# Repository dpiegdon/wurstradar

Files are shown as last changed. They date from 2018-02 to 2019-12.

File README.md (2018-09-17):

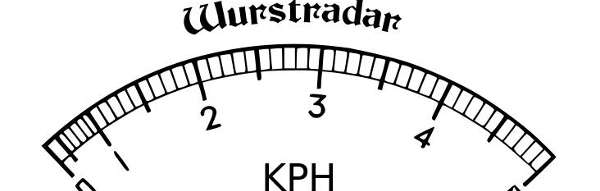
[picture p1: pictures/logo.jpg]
Wurstradar


Sausage radar. Simple doppler radar that fits into a sausage can.
Named after "Wurstblinker" from the german movie [Werner](https://www.youtube.com/watch?v=n31j2_dkaCo),
as it also is meant to be mounted on a motorcycle as an alternative to the speedometer.

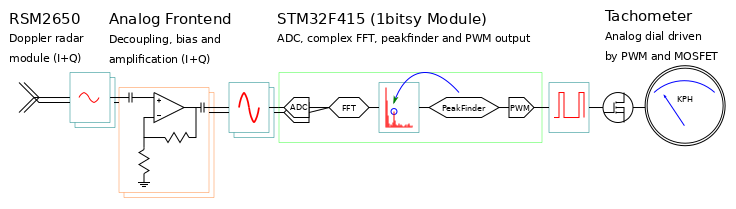
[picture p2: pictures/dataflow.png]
DataFlow


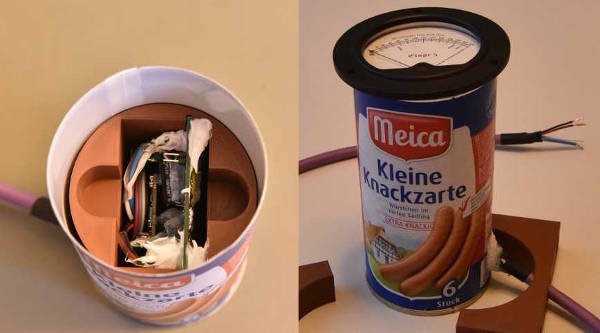
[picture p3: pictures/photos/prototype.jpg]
Prototype


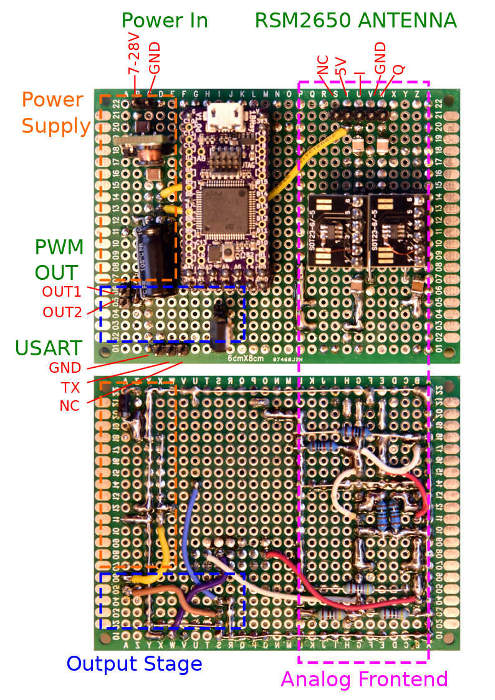
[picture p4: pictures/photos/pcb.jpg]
PCB


Required hardware
=================

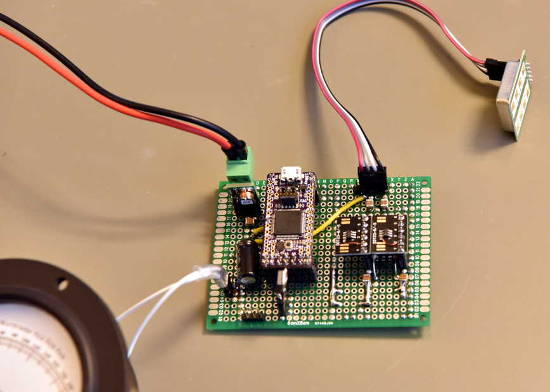
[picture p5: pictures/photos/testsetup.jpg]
TestSetup


RSM2650 Radar movement alarm unit (this probably is an Innosent IPS-265)

 * `http://www.produktinfo.conrad.com/datenblaetter/500000-524999/506343-da-01-en-RADARBEWEGUNGSM__MOD__STEREO_4_75__5_25V.pdf`
 * `https://www.innosent.de/fileadmin/media/dokumente/datasheets/IPS-265.pdf`

1bitsy STM32F415 on a tiny breakout board

 * `https://1bitsy.org/`

Used Simpson Voltmeter 5V as analog dial.

 * `https://www.google.de/search?q=simpson+5v+ac&tbm=isch`

Generic powerbrick to 5V

 * e.g. TI TPSM84205

A JTAG debugger.

 * e.g. Black Magic Probe

Required software
=================

Only `arm-none-eabi-gcc`.

Further plans and ideas
=======================

 * FMCW / Range Doppler (minor hardware change, complex firmware changes)

   The current antenna module (RSM2650) can be replaced with a module that supports a tuning
   voltage. Then, FMCW and Range-Doppler could be done. The tuning voltage could be supplied
   with the STM32 DAC, which already has some support code in the git history.

 * Improved signal quality and range (complex hardware changes)

   The analog frontend currently is a simple opamp amplifier with decoupling and biasing.
   Options are to increase the amplification, pick better opamps or dedicated LNAs.
   Automatic gain might me an option with that.

 * USB waveform output (simple firmware changes)

   Output both I and Q as a data stream via USB, so a connected computer can use them.

Compiling
=========

Clone first: `git clone --recursive https://github.com/dpiegdon/wurstradar.git`

Then build libopencm3: `cd wurstradar/libopencm3 && make`

Then build the firmware: `cd ../src && make` - 
you can set the measurement angle and its proper doppler frequency via
commandline: `make DOPPLER_HZ_PER_POINT1_KPH=314 MEASUREMENT_DEGREE=45`

Flash it to the 1bitsy. E.g. with a Black Magic Probe.

Team
====

 * David Owczarek - `david dot owczarek at googlemail dot com` - hardware

 * David R. Piegdon - [@dpiegdon](https://github.com/dpiegdon) - concept, firmware, hardware and assembly

 * Florian Schwanse - `florian at schwanse dot de` - 3d printed parts and case

 * Frank Terbeck - [@ft](https://github.com/ft) - concept and hardware

 * Iqbal Maraqa - `iqbal underscore maraqa at hotmail dot com` - analog dial face

 * Manoel Brunnen - [@mbrunnen](https://github.com/mbrunnen) - firmware

 * Martin Gritzan - [@mgritz](https://github.com/mgritz) - firmware

 * Sebastian Moenninghoff - `spsm at mailbox dot org` - 3d printed parts

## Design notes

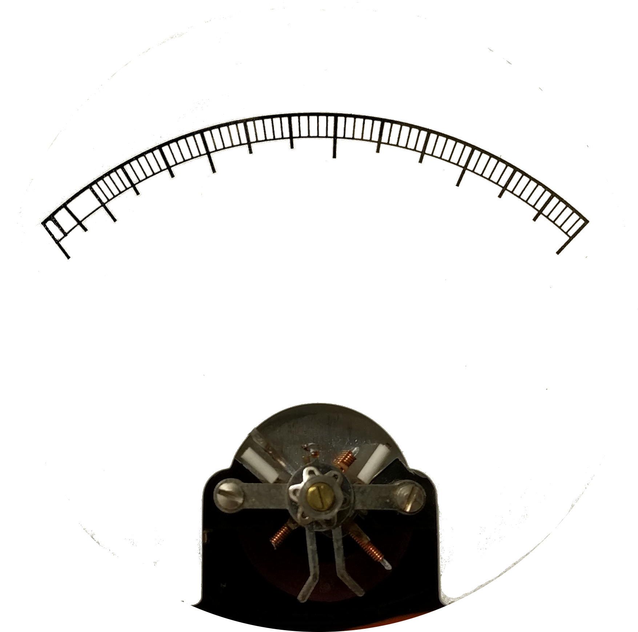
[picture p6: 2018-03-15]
pictures/faceplate/faceplate_scale.png

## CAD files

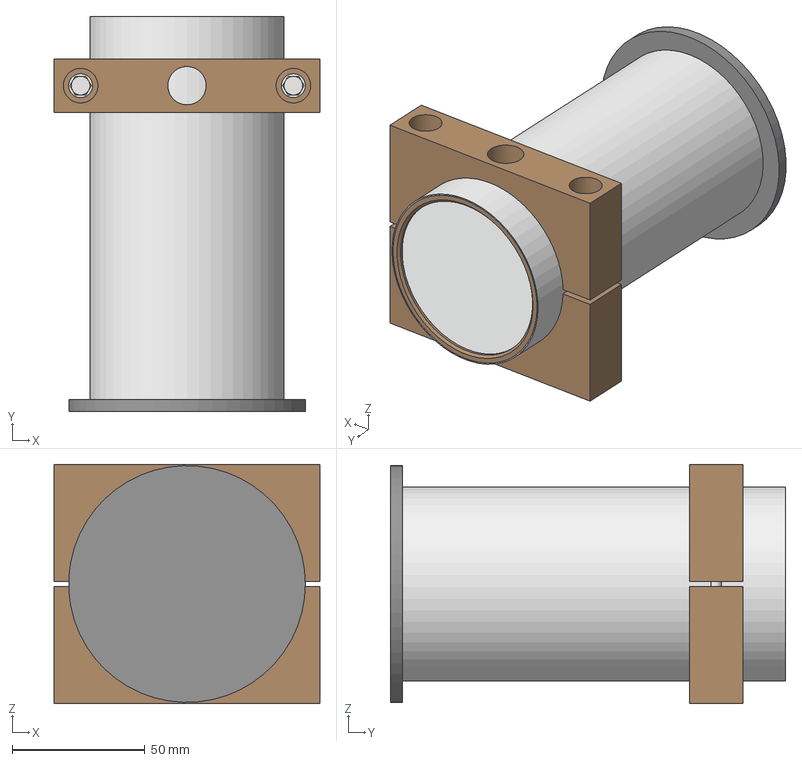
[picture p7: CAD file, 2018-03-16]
can-inlay/wurstradar_2018-03-15.stp
100.0 x 148.5 x 90.0 mm

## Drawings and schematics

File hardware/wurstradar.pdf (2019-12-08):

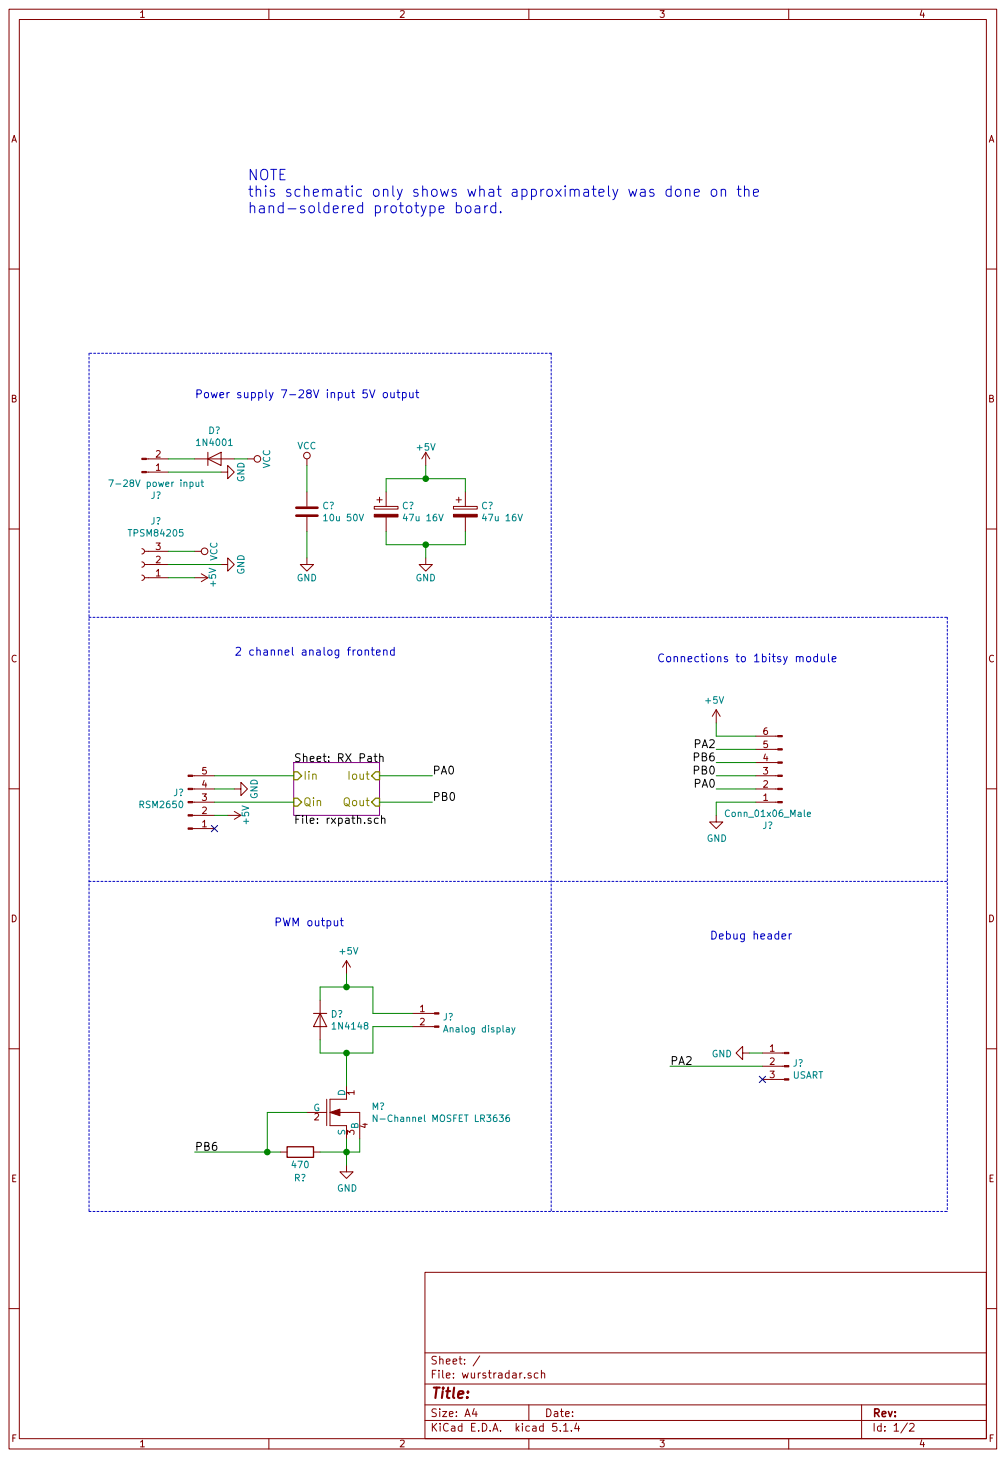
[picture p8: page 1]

NOTE
this schematic only shows what approximately was done on the
hand-soldered prototype board.

Power supply 7-28V input 5V output

47u 16V R? | J? Conn_01x06_Male GND +5V

PWM output +5V | | 1

Id: 1/2 Title: File: wurstradar.sch Sheet: /

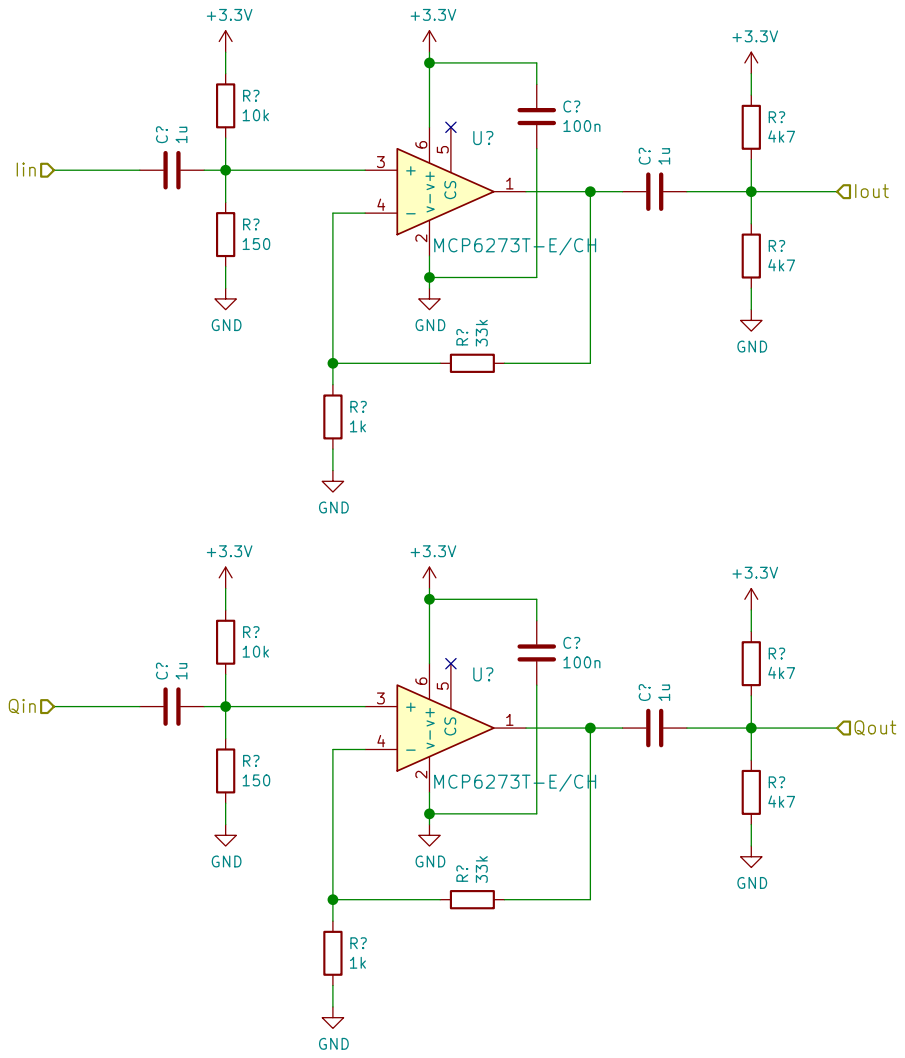
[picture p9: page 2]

File: rxpath.sch Sheet: /RX Path/

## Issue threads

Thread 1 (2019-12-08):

can't open the schematic file!

tek4ever, 2019-12-08:
what version of kiCad do you use for this schematic?

dpiegdon, 2019-12-08:
True, a current version of KiCad (5.1.4) required some remapping and a few things were unclear.
I updated the schematic and also exported as PDF.
But note that the schematic is only for documentation purposes. It is incomplete and only indicates what was done on the hand-soldered prototype-board.

Closed 2019-12-08.

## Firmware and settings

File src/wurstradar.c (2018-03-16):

#include <assert.h>
#include <errno.h>
#include <stdio.h>
#include <unistd.h>
#include <stdint.h>
#include <libopencm3/cm3/nvic.h>
#include <libopencm3/stm32/adc.h>
#include <libopencm3/stm32/dma.h>
#include <libopencm3/stm32/dac.h>
#include <libopencm3/stm32/gpio.h>
#include <libopencm3/stm32/rcc.h>
#include <libopencm3/stm32/usart.h>
#include <libopencm3/stm32/iwdg.h>
#include <libopencm3/stm32/timer.h>

#include <arm_math.h>
#include <arm_const_structs.h>



#define ARRAY_SIZE(arr) (sizeof(arr) / sizeof((arr)[0]))

#define stringify(s) xstringify(s)
#define xstringify(s) #s

#ifndef DOPPLER_HZ_PER_POINT1_KPH
# warning no defaults supplied for doppler hz/angle. using 0 degree angle.
// at 0 degree, doppler freq is 44.4Hz/kph. at 45 degree its 31.4Hz/kph
# define DOPPLER_HZ_PER_POINT1_KPH 444
# define MEASUREMENT_DEGREE 0
#endif

#define WAVESIZE 4096
#define HZ_PER_BIN			( 42688. / WAVESIZE )
#define KPH_PER_BIN			( (HZ_PER_BIN) / (DOPPLER_HZ_PER_POINT1_KPH/10.) )



int _write(int file, char *ptr, int len);

static void clock_setup(void)
{
	// Setup PLL and system clock to 168 MHz.
	rcc_clock_setup_hse_3v3(&rcc_hse_25mhz_3v3[RCC_CLOCK_3V3_168MHZ]);

	rcc_periph_clock_enable(RCC_GPIOA);
	rcc_periph_clock_enable(RCC_GPIOB);
	rcc_periph_clock_enable(RCC_USART2);

	rcc_periph_clock_enable(RCC_ADC1);
	rcc_periph_clock_enable(RCC_ADC2);
	rcc_periph_clock_enable(RCC_DMA2);

	rcc_periph_clock_enable(RCC_TIM4);
	rcc_periph_clock_enable(RCC_DAC);
}

static void wdt_setup(void)
{
	iwdg_set_period_ms(1000);
	iwdg_start();
}

static void wdt_trigger(void)
{
	iwdg_reset();
}

static void led_setup(void)
{
	// Setup LED1 on PA8.
	gpio_mode_setup(GPIOA, GPIO_MODE_OUTPUT, GPIO_PUPD_NONE, GPIO8);

	// additional GPIOs for debugging output
	gpio_mode_setup(GPIOB, GPIO_MODE_OUTPUT, GPIO_PUPD_NONE, GPIO13);
	gpio_mode_setup(GPIOB, GPIO_MODE_OUTPUT, GPIO_PUPD_NONE, GPIO14);
	gpio_mode_setup(GPIOB, GPIO_MODE_OUTPUT, GPIO_PUPD_NONE, GPIO15);
}

static void led_toggle(void)
{
	/* LED on/off */
	gpio_toggle(GPIOA, GPIO8);
}

static void pb13_toggle(void)
{
	gpio_toggle(GPIOB, GPIO13);
}

static void pb14_toggle(void)
{
	gpio_toggle(GPIOB, GPIO14);
}

static void pb15_toggle(void)
{
	gpio_toggle(GPIOB, GPIO15);
}

static void usart_setup(void)
{
	// Setup USART ouput on pin PA2.
	gpio_mode_setup(GPIOA, GPIO_MODE_AF, GPIO_PUPD_NONE, GPIO2);
	gpio_set_af(GPIOA, GPIO_AF7, GPIO2);
	usart_set_baudrate(USART2, 921600);
	usart_set_databits(USART2, 8);
	usart_set_stopbits(USART2, USART_STOPBITS_1);
	usart_set_mode(USART2, USART_MODE_TX);
	usart_set_parity(USART2, USART_PARITY_NONE);
	usart_set_flow_control(USART2, USART_FLOWCONTROL_NONE);
	usart_enable(USART2);
}

/**
 * Use USART2 as a console.
 * This is a syscall for newlib
 * @param file
 * @param ptr
 * @param len
 * @return
 */
int _write(int file, char *ptr, int len)
{
	int i;

	if (file == STDOUT_FILENO || file == STDERR_FILENO) {
		for (i = 0; i < len; i++) {
			if (ptr[i] == '\n') {
				usart_send_blocking(USART2, '\r');
			}
			usart_send_blocking(USART2, ptr[i]);
		}
		return i;
	}
	errno = EIO;
	return -1;
}

static uint32_t waveform1[WAVESIZE];
static uint32_t waveform2[WAVESIZE];
static uint32_t * waveform_to_process = NULL;
static volatile int waveform_ready = 0;

static void dma_setup(void)
{
	// Setup ADC1 DMA transfers via DMA2 Stream 0 Channel 0
	dma_stream_reset(DMA2, DMA_STREAM0);
	dma_channel_select(DMA2, DMA_STREAM0, DMA_SxCR_CHSEL_0);
	dma_set_priority(DMA2, DMA_STREAM0, DMA_SxCR_PL_MEDIUM);

	dma_set_transfer_mode(DMA2, DMA_STREAM0, DMA_SxCR_DIR_PERIPHERAL_TO_MEM);

	dma_set_peripheral_size(DMA2, DMA_STREAM0, DMA_SxCR_PSIZE_32BIT);
	dma_set_peripheral_address(DMA2, DMA_STREAM0, (uint32_t) &ADC_CDR);
	dma_set_number_of_data(DMA2, DMA_STREAM0, WAVESIZE);

	dma_set_memory_size(DMA2, DMA_STREAM0, DMA_SxCR_MSIZE_32BIT);
	dma_set_memory_address(DMA2, DMA_STREAM0, (uint32_t) waveform1);
	dma_set_memory_address_1(DMA2, DMA_STREAM0, (uint32_t) waveform2);
	dma_set_initial_target(DMA2, DMA_STREAM0, 0);
	dma_disable_peripheral_increment_mode(DMA2, DMA_STREAM0);
	dma_enable_memory_increment_mode(DMA2, DMA_STREAM0);

	dma_enable_circular_mode(DMA2, DMA_STREAM0);
	dma_enable_double_buffer_mode(DMA2, DMA_STREAM0);

	dma_enable_transfer_complete_interrupt(DMA2, DMA_STREAM0);
	nvic_enable_irq(NVIC_DMA2_STREAM0_IRQ);

	dma_enable_stream(DMA2, DMA_STREAM0);
}

static void adc_setup(void)
{
	// Setup ADC1_IN0 on PA0 and ADC2_IN8 on PB0.
	// sampling at ~42688 SPS.
	// (actually should be 168/2 / 4 / 480 = 43750 SPS)
	uint8_t adc1_channels[] = { ADC_CHANNEL0 };
	uint8_t adc2_channels[] = { ADC_CHANNEL8 };

	gpio_mode_setup(GPIOA, GPIO_MODE_ANALOG, GPIO_PUPD_NONE, GPIO0);
	gpio_mode_setup(GPIOB, GPIO_MODE_ANALOG, GPIO_PUPD_NONE, GPIO0);

	adc_power_off(ADC1);
	adc_power_off(ADC2);

	adc_disable_scan_mode(ADC1);
	adc_disable_scan_mode(ADC2);

	adc_disable_external_trigger_regular(ADC1);
	adc_disable_external_trigger_regular(ADC2);

	adc_set_clk_prescale(ADC_CCR_ADCPRE_BY4);

	adc_set_sample_time_on_all_channels(ADC1, ADC_SMPR_SMP_480CYC);
	adc_set_sample_time_on_all_channels(ADC2, ADC_SMPR_SMP_480CYC);

	adc_set_resolution(ADC1, ADC_CR1_RES_12BIT);
	adc_set_resolution(ADC2, ADC_CR1_RES_12BIT);

	adc_set_right_aligned(ADC1);
	adc_set_right_aligned(ADC2);

	adc_set_regular_sequence(ADC1, ARRAY_SIZE(adc1_channels), adc1_channels);
	adc_set_regular_sequence(ADC2, ARRAY_SIZE(adc2_channels), adc2_channels);

	adc_set_continuous_conversion_mode(ADC1);
	adc_set_continuous_conversion_mode(ADC2);

	// Setup dual multi mode for ADC1+ADC2 with DMA
	ADC_CCR &= (~ADC_CCR_MULTI_MASK) | (~ADC_CCR_DMA_MASK);
	ADC_CCR |= ADC_CCR_MULTI_DUAL_REGULAR_SIMUL | ADC_CCR_DMA_MODE_2;

	// enable automatic DMA requests after conversion
	adc_enable_dma(ADC1);

	// continue sending DMA requests even if DMA controller is no longer
	// configured for DMA. needed to support circular buffers
	adc_set_dma_continue(ADC1);

	dma_setup();

	adc_power_on(ADC1);
	adc_power_on(ADC2);
}

uint32_t dma_sample_todo = 0;
void dma2_stream0_isr(void)
{
	dma_clear_interrupt_flags(DMA2, DMA_STREAM0, DMA_TCIF);
	pb13_toggle();

	dma_sample_todo = DMA2_SNDTR(DMA_STREAM0);

	if(0 == dma_get_target(DMA2, DMA_STREAM0))
		waveform_to_process = waveform2;
	else
		waveform_to_process = waveform1;
	waveform_ready = 1;

}

static void pwm_setup(void)
{
	// configure PWM on TIM4CHAN1 on PB6
	gpio_mode_setup(GPIOB, GPIO_MODE_AF, GPIO_PUPD_NONE, GPIO6);
	gpio_set_af(GPIOB, GPIO_AF2, GPIO6);

	timer_reset(TIM4);
	// Timer global mode:
	// - Sampling clock divider 1
	// - Alignment edge
	// - Direction up
	timer_set_mode(TIM4, TIM_CR1_CKD_CK_INT, TIM_CR1_CMS_EDGE, TIM_CR1_DIR_UP);
	// Prescaler for input clock (half of the core clock aka 84MHz)
	timer_set_prescaler(TIM4, 32);
	// Enable preload.
	timer_disable_preload(TIM4);
	// Continous mode.
	timer_continuous_mode(TIM4);
	// Period (84MHz/16/65535) = ~ 40 Hz
	timer_set_period(TIM4, 0xFFFF);
	// Disable outputs.
	timer_disable_oc_output(TIM4, TIM_OC1);
	timer_disable_oc_output(TIM4, TIM_OC2);
	timer_disable_oc_output(TIM4, TIM_OC3);
	timer_disable_oc_output(TIM4, TIM_OC4);
	// OC1 configuration
	// Configure global mode of line 1.
	timer_disable_oc_clear(TIM4, TIM_OC1);
	timer_enable_oc_preload(TIM4, TIM_OC1);
	timer_set_oc_slow_mode(TIM4, TIM_OC1);
	timer_set_oc_mode(TIM4, TIM_OC1, TIM_OCM_PWM1);
	timer_set_oc_polarity_high(TIM4, TIM_OC1);
	// Set the capture compare value for OC1 to half of the period to achieve 50% duty cycle.
	timer_set_oc_value(TIM4, TIM_OC1, 0xFFFF/2);
	timer_enable_oc_output(TIM4, TIM_OC1);
	timer_enable_preload(TIM4);
	// Counter enable.
	timer_enable_counter(TIM4);
}

static void pwm_output(uint16_t value)
{
	// set duty cycle
	timer_set_oc_value(TIM4, TIM_OC1, value);
}

static void platform_init(void)
{
	clock_setup();
	wdt_setup();
	led_setup();
	usart_setup();
	adc_setup();
	pwm_setup();
}

struct fft_length_config_entry {
	uint32_t len;
	const arm_cfft_instance_q15 * config;
};

uint16_t output_per_10kph[] = { // valid for 40Hz PWM
	0x0000,	//   0 kph
	0x0c94,	//  10
	0x1441,	//  20
	0x1928,	//  30
	0x1e46,	//  40
	0x239b,	//  50
	0x28ef,	//  60
	0x2ff8,	//  70
	0x3627,	//  80
	0x3d67,	//  90
	0x443a,	// 100
	0x4c1d,	// 110
	0x53ca,	// 120
	0x5c88,	// 130
	0x6620,	// 140
	0x7040,	// 150
	0x7b05,	// 160
	0x8541,	// 170
	0x9021,	// 180
	0x9b37,	// 190
	0xa728,	// 200
	0xb3f3,	// 210
	0xc050,	// 220
	0xcc41,	// 230
	0xd900	// 240 kph
};

static void process_waveform(void)
{
	unsigned i;
	unsigned toward;

	// get FFT
	assert(WAVESIZE == 4096);
	arm_cfft_q15(&arm_cfft_sR_q15_len4096, (q15_t*)waveform_to_process, 0, 1);

	// find / track peak
	int16_t *wav = (int16_t*)waveform_to_process;
	int16_t peak_magnitude=0, peak_index=0;
	for(i = 20; i < WAVESIZE-20; ++i) {
		int16_t mag = wav[2*i+0] * wav[2*i+0]  +  wav[2*i+1] * wav[2*i+1];
		if(peak_magnitude < mag) {
			peak_magnitude = mag;
			peak_index = i;
		}
	}

	if(peak_index >= WAVESIZE/2) {
		toward = 1;
		peak_index = WAVESIZE - peak_index;
	} else {
		toward = 0;
	}

	if(peak_magnitude < 0x10) {
		toward = 1;
		peak_index = 0;
	}

	unsigned int speed = (peak_index * (int)(HZ_PER_BIN*10) ) / (int)DOPPLER_HZ_PER_POINT1_KPH;

	unsigned int index_low  = speed/10;
	if(index_low >= ARRAY_SIZE(output_per_10kph))
		index_low = ARRAY_SIZE(output_per_10kph)-1;
	unsigned int index_high = index_low+1;
	if(index_high >= ARRAY_SIZE(output_per_10kph))
		index_high = ARRAY_SIZE(output_per_10kph)-1;

	uint16_t span_low  = output_per_10kph[index_low];
	uint16_t span_high = output_per_10kph[index_high];
	uint16_t delta = span_high - span_low;
	uint16_t output = span_low + (delta * (speed % 10)) / 10;

#if 1
	printf("fft bin %4d mag^2 %04x speed %c%u kph output 0x%04x\n",
			peak_index, peak_magnitude, toward ? '+' : '-', speed, output);
#endif

	pwm_output(output);
}

int main(void)
{
	platform_init();

	printf( "\n"
		"ETAGE5 WURSTRADAR\n"
		"Version " stringify(VERSION) " (git " stringify(GIT_VERSION) ")\n"
		"2018 by David, David, Frank, Iqbal, Manoel, Martin, Florian.\n"
		"Configured for " stringify(MEASUREMENT_DEGREE) " degree to moving target.\n"
		"\n");

	adc_start_conversion_regular(ADC1);
	adc_start_conversion_regular(ADC2);

	while (1) {
		if(waveform_ready) {
			pb13_toggle();
			pb14_toggle();
			waveform_ready = 0;
			wdt_trigger();
			process_waveform();
			pb14_toggle();
			pb15_toggle();
			led_toggle();
			__WFI();
		}
	}

	return 0;
}

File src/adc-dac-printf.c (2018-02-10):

/*
 * This file is part of the libopencm3 project.
 *
 * Copyright (C) 2014 Karl Palsson <karlp@tweak.net.au>
 *
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
 * You should have received a copy of the GNU Lesser General Public License
 * along with this library.  If not, see <http://www.gnu.org/licenses/>.
 */

#include <errno.h>
#include <stdio.h>
#include <unistd.h>
#include <libopencm3/cm3/nvic.h>
#include <libopencm3/stm32/adc.h>
#include <libopencm3/stm32/dac.h>
#include <libopencm3/stm32/gpio.h>
#include <libopencm3/stm32/rcc.h>
#include <libopencm3/stm32/usart.h>

#define LED_DISCO_GREEN_PORT GPIOD
#define LED_DISCO_GREEN_PIN GPIO12

#define USART_CONSOLE USART2

int _write(int file, char *ptr, int len);

static void clock_setup(void)
{
	rcc_clock_setup_hse_3v3(&rcc_hse_8mhz_3v3[RCC_CLOCK_3V3_168MHZ]);
	/* Enable GPIOD clock for LED & USARTs. */
	rcc_periph_clock_enable(RCC_GPIOD);
	rcc_periph_clock_enable(RCC_GPIOA);

	/* Enable clocks for USART2 and dac */
	rcc_periph_clock_enable(RCC_USART2);
	rcc_periph_clock_enable(RCC_DAC);

	/* And ADC*/
	rcc_periph_clock_enable(RCC_ADC1);
}

static void usart_setup(void)
{
	/* Setup GPIO pins for USART2 transmit. */
	gpio_mode_setup(GPIOA, GPIO_MODE_AF, GPIO_PUPD_NONE, GPIO2);

	/* Setup USART2 TX pin as alternate function. */
	gpio_set_af(GPIOA, GPIO_AF7, GPIO2);

	usart_set_baudrate(USART_CONSOLE, 115200);
	usart_set_databits(USART_CONSOLE, 8);
	usart_set_stopbits(USART_CONSOLE, USART_STOPBITS_1);
	usart_set_mode(USART_CONSOLE, USART_MODE_TX);
	usart_set_parity(USART_CONSOLE, USART_PARITY_NONE);
	usart_set_flow_control(USART_CONSOLE, USART_FLOWCONTROL_NONE);

	/* Finally enable the USART. */
	usart_enable(USART_CONSOLE);
}

/**
 * Use USART_CONSOLE as a console.
 * This is a syscall for newlib
 * @param file
 * @param ptr
 * @param len
 * @return
 */
int _write(int file, char *ptr, int len)
{
	int i;

	if (file == STDOUT_FILENO || file == STDERR_FILENO) {
		for (i = 0; i < len; i++) {
			if (ptr[i] == '\n') {
				usart_send_blocking(USART_CONSOLE, '\r');
			}
			usart_send_blocking(USART_CONSOLE, ptr[i]);
		}
		return i;
	}
	errno = EIO;
	return -1;
}

static void adc_setup(void)
{
	gpio_mode_setup(GPIOA, GPIO_MODE_ANALOG, GPIO_PUPD_NONE, GPIO0);
	gpio_mode_setup(GPIOA, GPIO_MODE_ANALOG, GPIO_PUPD_NONE, GPIO1);

	adc_power_off(ADC1);
	adc_disable_scan_mode(ADC1);
	adc_set_sample_time_on_all_channels(ADC1, ADC_SMPR_SMP_3CYC);

	adc_power_on(ADC1);

}

static void dac_setup(void)
{
	gpio_mode_setup(GPIOA, GPIO_MODE_ANALOG, GPIO_PUPD_NONE, GPIO5);
	dac_disable(CHANNEL_2);
	dac_disable_waveform_generation(CHANNEL_2);
	dac_enable(CHANNEL_2);
	dac_set_trigger_source(DAC_CR_TSEL2_SW);
}

static uint16_t read_adc_naiive(uint8_t channel)
{
	uint8_t channel_array[16];
	channel_array[0] = channel;
	adc_set_regular_sequence(ADC1, 1, channel_array);
	adc_start_conversion_regular(ADC1);
	while (!adc_eoc(ADC1));
	uint16_t reg16 = adc_read_regular(ADC1);
	return reg16;
}

int main(void)
{
	int i;
	int j = 0;
	clock_setup();
	usart_setup();
	printf("hi guys!\n");
	adc_setup();
	dac_setup();

	/* green led for ticking */
	gpio_mode_setup(LED_DISCO_GREEN_PORT, GPIO_MODE_OUTPUT, GPIO_PUPD_NONE,
			LED_DISCO_GREEN_PIN);

	while (1) {
		uint16_t input_adc0 = read_adc_naiive(0);
		uint16_t target = input_adc0 / 2;
		dac_load_data_buffer_single(target, RIGHT12, CHANNEL_2);
		dac_software_trigger(CHANNEL_2);
		uint16_t input_adc1 = read_adc_naiive(1);
		printf("tick: %d: adc0= %u, target adc1=%d, adc1=%d\n",
			j++, input_adc0, target, input_adc1);

		/* LED on/off */
		gpio_toggle(LED_DISCO_GREEN_PORT, LED_DISCO_GREEN_PIN);

		for (i = 0; i < 1000000; i++) { /* Wait a bit. */
			__asm__("NOP");
		}
	}

	return 0;
}

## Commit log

2018-02-09 notes on radar sensor
2018-02-10 implemented adc-dac-printf example for stm32f4
2018-02-11 figure out ADC setup
2018-02-12 adc DMA draft (not working)
    [wurstradar.c]
2018-02-12 use correct ADC channel for PA0
    [wurstradar.c]
2018-02-13 draft schematic for single rx path
    [wurstradar.kicad_pcb, wurstradar.sch]
2018-02-14 verified rx path schematic in ltspice, fixed some values
    [wurstradar.sch]
2018-02-20 hardware preps for pcb
    [rxpath.sch, wurstradar.sch]
2018-02-25 wrapper for fft computation
    We can compute the complex fft of our ADCed samples directly because I
    and Q are placed within 4-byte words together.
    This is assuming the DMA does always return enough samples for our fft
    to be meaningful. We select the next lower power of two to compute,
    though.
2018-02-27 Revert "Enable semihosting"
    This reverts commit 3e55c9a228a6f1f18c703e2898543b9fba4018cb.
    Semihosting has a longer latency than 2Mbaud UART.
    Hence the DMA contraption crashes. Reverted it to progress.
    [wurstradar.c]
2018-02-27 set correct DEVICE
    Doesn't help; though
2018-02-27 Reordered DMA init
    As suggested in the Reference Manual Section 10.3.17
2018-02-27 dma stuff in own function
2018-02-27 shorter sampling time
    as suggested by CubeMX
    [wurstradar.c]
2018-02-27 adc data right-aligned
2018-02-27 corrected ADC_CCR flags
    as suggested by CubeMX and datashit but not implemented on libopencm3...
    [wurstradar.c]
2018-02-27 updated schematic to current
    [rxpath.sch, wurstradar.sch]
2018-03-15 integrate FFT library (dunno if it works...)
    [wurstradar.sch]
2018-03-15 support PWM on PB6, setting duty cycle
2018-03-15 disable interleaved waiting for DMA
2018-03-15 fix concurrent DMA issue: enable ADC2 power (DOH!)
    [wurstradar.c]
2018-03-15 fix scaling, do manual complex2mag, do proper scaling and output
    [wurstradar.c]
2018-03-15 double PWM frequency
2018-03-15 cut off more lower frequencies and ignore them when finding maxbin.
2018-03-15 openocd config; increase pwm freq; calibration?
2018-03-15 prescale TIM4 so PWM freq is 40Hz. that reduces flickering due to pwm-freq influence on radar signal.
2018-03-15 provide calibration table to compensate for non-linear elements in output
2018-03-15 added Florian Schwanses 3d model of the inlay - first (and obsolete) version
    [Zack-Zack.ipt, Zack-Zack_2018-03-02.stl, Zack-Zack_2018-03-02.stp]
2018-03-15 switch to 45 degree. also show configuration during startup. also show authors/builders during startup.
2018-03-15 version 1.0.0 - configurable angle, properly print version, credits and angle on startup
2018-03-16 latest inlay STL file
    [Zack-Zack.ipt, Zack-Zack_2018-03-02.stl, Zack-Zack_2018-03-02.stp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]
2018-03-16 power-save when idle
2019-12-08 for long-term documentation: cleanup and port schematic to Kicad v5.1.4 and also export as PDF.
    [rxpath.sch, wurstradar.kicad_pcb, wurstradar.sch]
2019-12-08 while at it, replace box-mosfet with a proper symbol
    [wurstradar.sch]

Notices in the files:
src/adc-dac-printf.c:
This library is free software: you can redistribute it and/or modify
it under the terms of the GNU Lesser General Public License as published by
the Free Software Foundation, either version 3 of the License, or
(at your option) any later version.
